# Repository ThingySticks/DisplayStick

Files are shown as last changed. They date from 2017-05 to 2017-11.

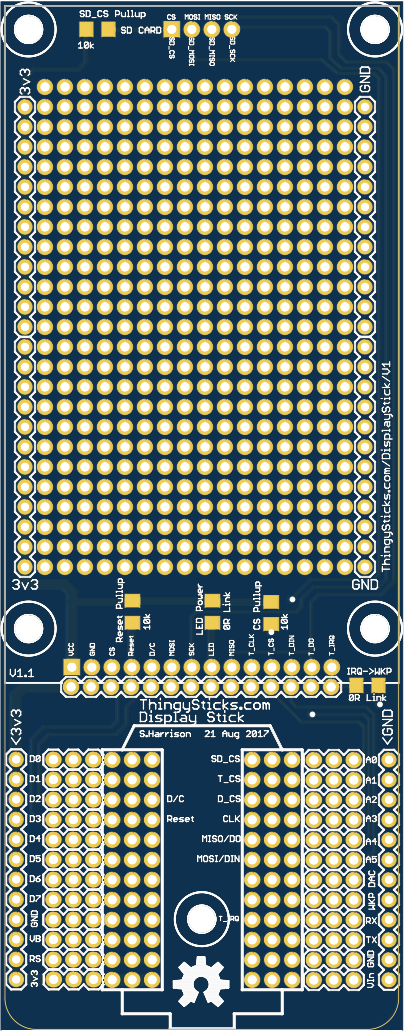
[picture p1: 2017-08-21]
Photon/V1/Images/PcbTop.png

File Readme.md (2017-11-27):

Photon Display Prototyping PCB.
================================

Prototype board for Particle Photon with 3.2" (eBay) display with prototype area underneath.

See individual versions for PCB specifics.

[Available on Tindie](https://www.tindie.com/products/ThingySticks/display-stick-for-a-28-display-and-photon/)

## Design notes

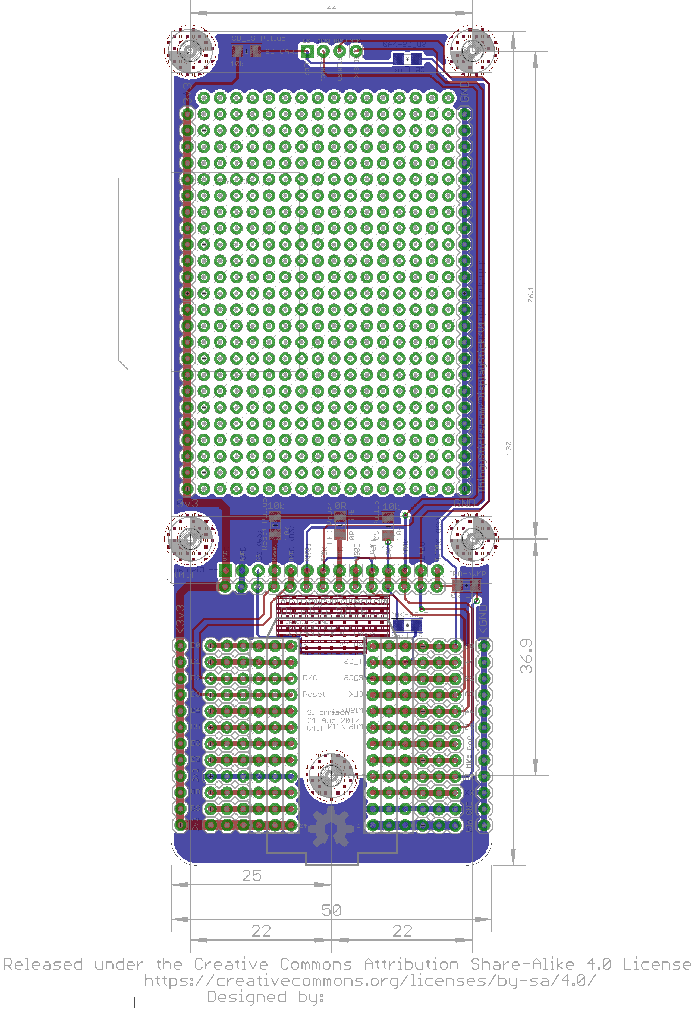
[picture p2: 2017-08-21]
Photon/V1/Images/PCBAllDesign.png

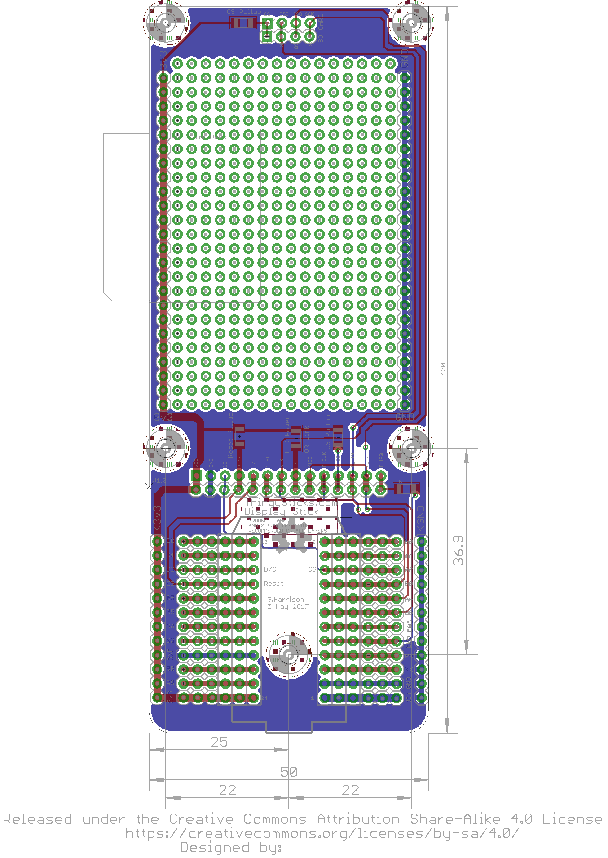
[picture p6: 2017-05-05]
Photon/V1/Images/v1.0/PCB-All.png

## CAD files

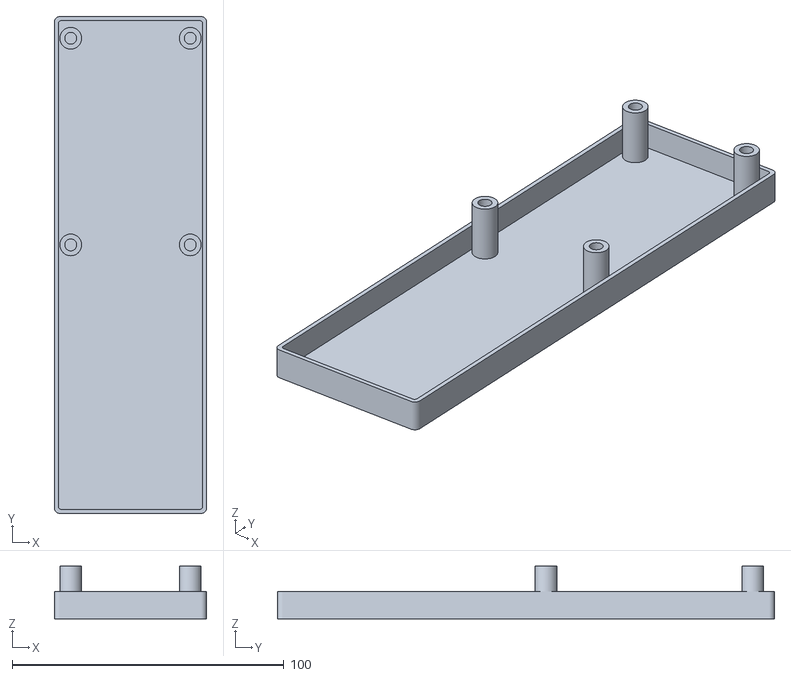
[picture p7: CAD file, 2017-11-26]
Photon/V1/Case/DisplayStickCaseForGPS.stl
56.0 x 183.0 x 19.4

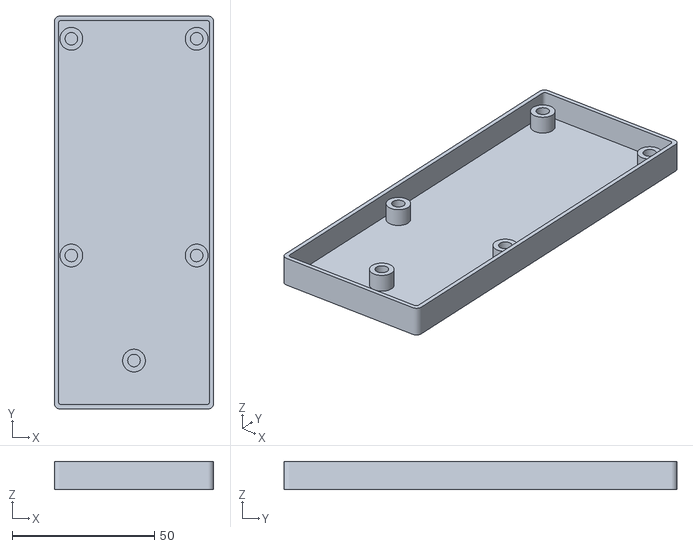
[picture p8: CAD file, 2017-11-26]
Photon/V1/Case/DisplayStickCase.stl
56.0 x 138.0 x 10.0

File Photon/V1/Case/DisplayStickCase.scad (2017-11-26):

$fn=80;

// Width (Note pcb does not centre align).
width = 56;

// Overall length /mm (without aerial 117mm, With aerial 125mm)
//length = 138;
length = 138 + 45; // with GPS

// Thickness of the base material.
baseHeight = 1.5;

// How height off the base the PCB wil lbe.
// 8mm gives a space for pins on the PCB
// used when piggubacking other pcbs.
//height = 8;
height = 18; // With GPS

//pcbYOffset = 3;
pcbYOffset = 3 + 45; // with GPS

incluedGpsModule = true;
// If including GPS raise height and length

// Diameter of the screw hole for the PCB mounts. 4.4mm works well for M3 heatfits.
pcbMountScrewHoleDiameter = 4.4;

// Diameter of the pins used to locate the PCB instead of screw holes.
pcbMountPinDiameter = 2.8;

module roundedCube(width, height, depth, cornerDiameter) {
//cornerDiameter = 5;
cornerRadius = cornerDiameter/2;

    translate([cornerDiameter/2,0,0]) {
        cube([width-cornerDiameter, height, depth]);
    }
    
    translate([0,cornerDiameter/2,0]) {
        cube([width, height-cornerDiameter, depth]);
    }
    
    translate([cornerRadius,cornerRadius,0]) {
        cylinder(d=cornerDiameter, h=depth);
    }
    
    translate([width-cornerRadius,cornerRadius,0]) {
        cylinder(d=cornerDiameter, h=depth);
    }
    
    translate([cornerRadius,height-cornerRadius,0]) {
        cylinder(d=cornerDiameter, h=depth);
    }
    
    translate([width-cornerRadius,height-cornerRadius,0]) {
        cylinder(d=cornerDiameter, h=depth);
    }
}

module screw(x,y, height) {
    translate([x,y, 0]) {
        cylinder(d=6.5, h=2);
    }
    
    translate([x,y, -4]) {
        cylinder(d=3, h=6);
    }
}

module pcb() {
    cube([50,130,1.6]);
    
    // Photon Screw mount
    screw(25, 14, height, baseHeight);
    
    // Display mounts.
    screw(3,14+36.9, height, baseHeight);
    screw(47,14+36.9, height, baseHeight);
    screw(3,14+36.9+76.1, height, baseHeight);
    screw(47,14+36.9+76.1, height, baseHeight);
}

module photon() {
    cube([20,38,13]);
        
    // USB
    translate([(20 - 8)/2, 0, 13]) {
        cube([8,5.5,3]);
    }
    
    // USB Plug
    translate([(20 - 12)/2, -20, 10]) {
        cube([12,22,7]);
    }
}

module display() {
    cube([50,85,13]);
}

module pcbMount(x,y, height, baseHeight) {
    translate([x,y, baseHeight-0.1]) {
        difference() {
            cylinder(d=8, h=height);
            cylinder(d=pcbMountScrewHoleDiameter, h=height);
        }
    }
}

module pcbMountPin(x,y, height, baseHeight) {
    translate([x,y, baseHeight-0.1]) {
        union() {
            cylinder(d=10, h=height);
            cylinder(d=pcbMountPinDiameter, h=height + 3);
        }
    }
}

module addPcbMounts() {
    // Use pins on the end two to make it easier to 
    
    // Photon Screw mount
    if (!incluedGpsModule) {
        pcbMount(25, 14, height, baseHeight);
    }
    
    // Display mounts.
    pcbMount(3,14+36.9, height, baseHeight);
    pcbMount(47,14+36.9, height, baseHeight);
    pcbMount(3,14+36.9+76.1, height, baseHeight);
    pcbMount(47,14+36.9+76.1, height, baseHeight);
}

module base() {       

    difference() {
        roundedCube(width, length, 10, 4);
        translate([1.5,1.5,baseHeight]) {
            roundedCube(width-3, length-3, 11, 2);
        }
    }
        
    
    translate([3,pcbYOffset,0]) {
        addPcbMounts();
    }
}

base();
showModels();

module showModels() {
    // Wall offset inside the box.
    translate([3,pcbYOffset,0]) {
        translate([0,0, baseHeight + height]) {
            %pcb();
        }

        translate([(50-20)/2, 0,  baseHeight + height + 1.6]) {
            %photon();
        }

        translate([0, 130 - 85, baseHeight + height + 1.6]) {
            %display();
        }
    }
}

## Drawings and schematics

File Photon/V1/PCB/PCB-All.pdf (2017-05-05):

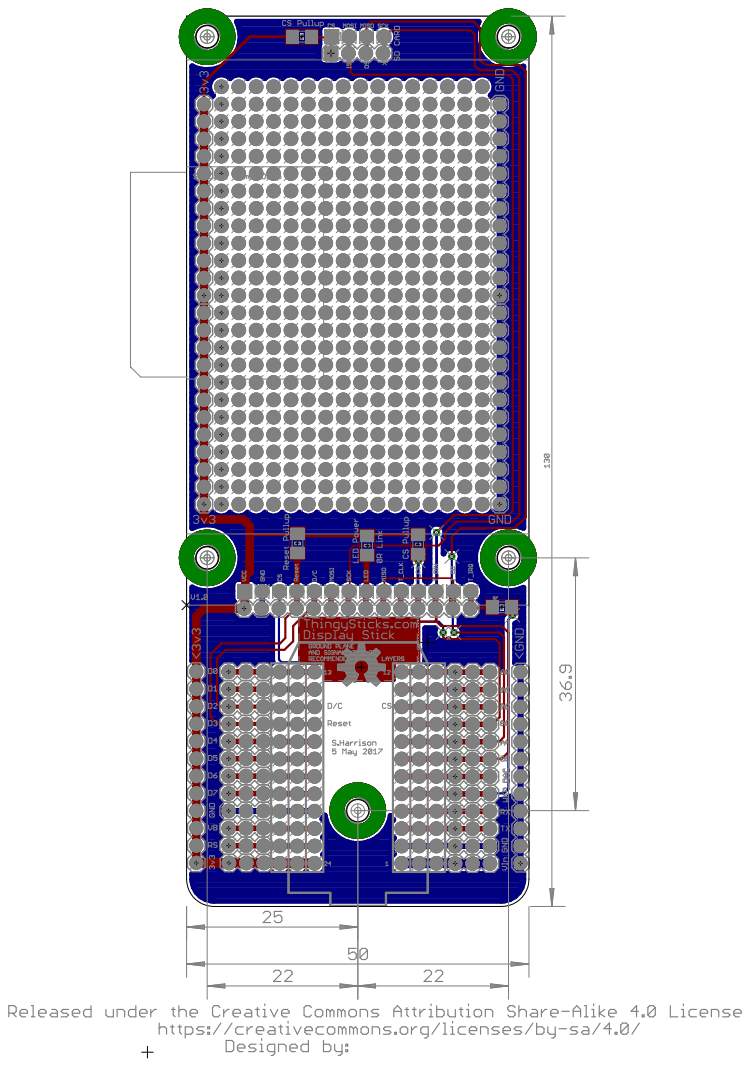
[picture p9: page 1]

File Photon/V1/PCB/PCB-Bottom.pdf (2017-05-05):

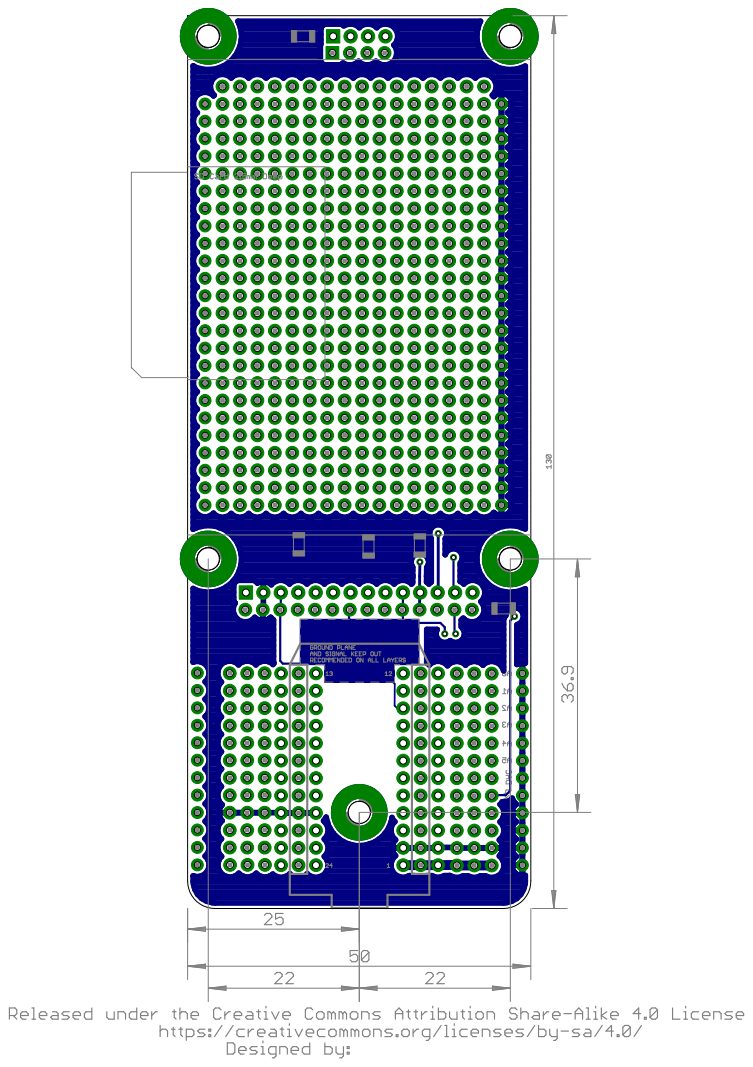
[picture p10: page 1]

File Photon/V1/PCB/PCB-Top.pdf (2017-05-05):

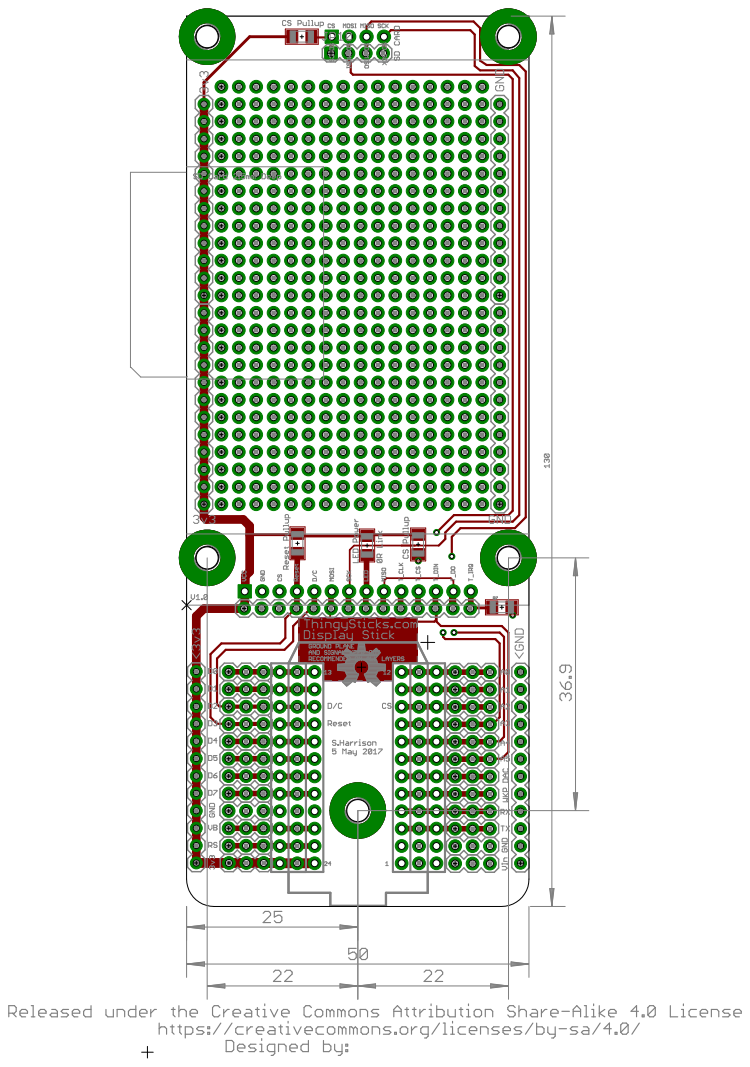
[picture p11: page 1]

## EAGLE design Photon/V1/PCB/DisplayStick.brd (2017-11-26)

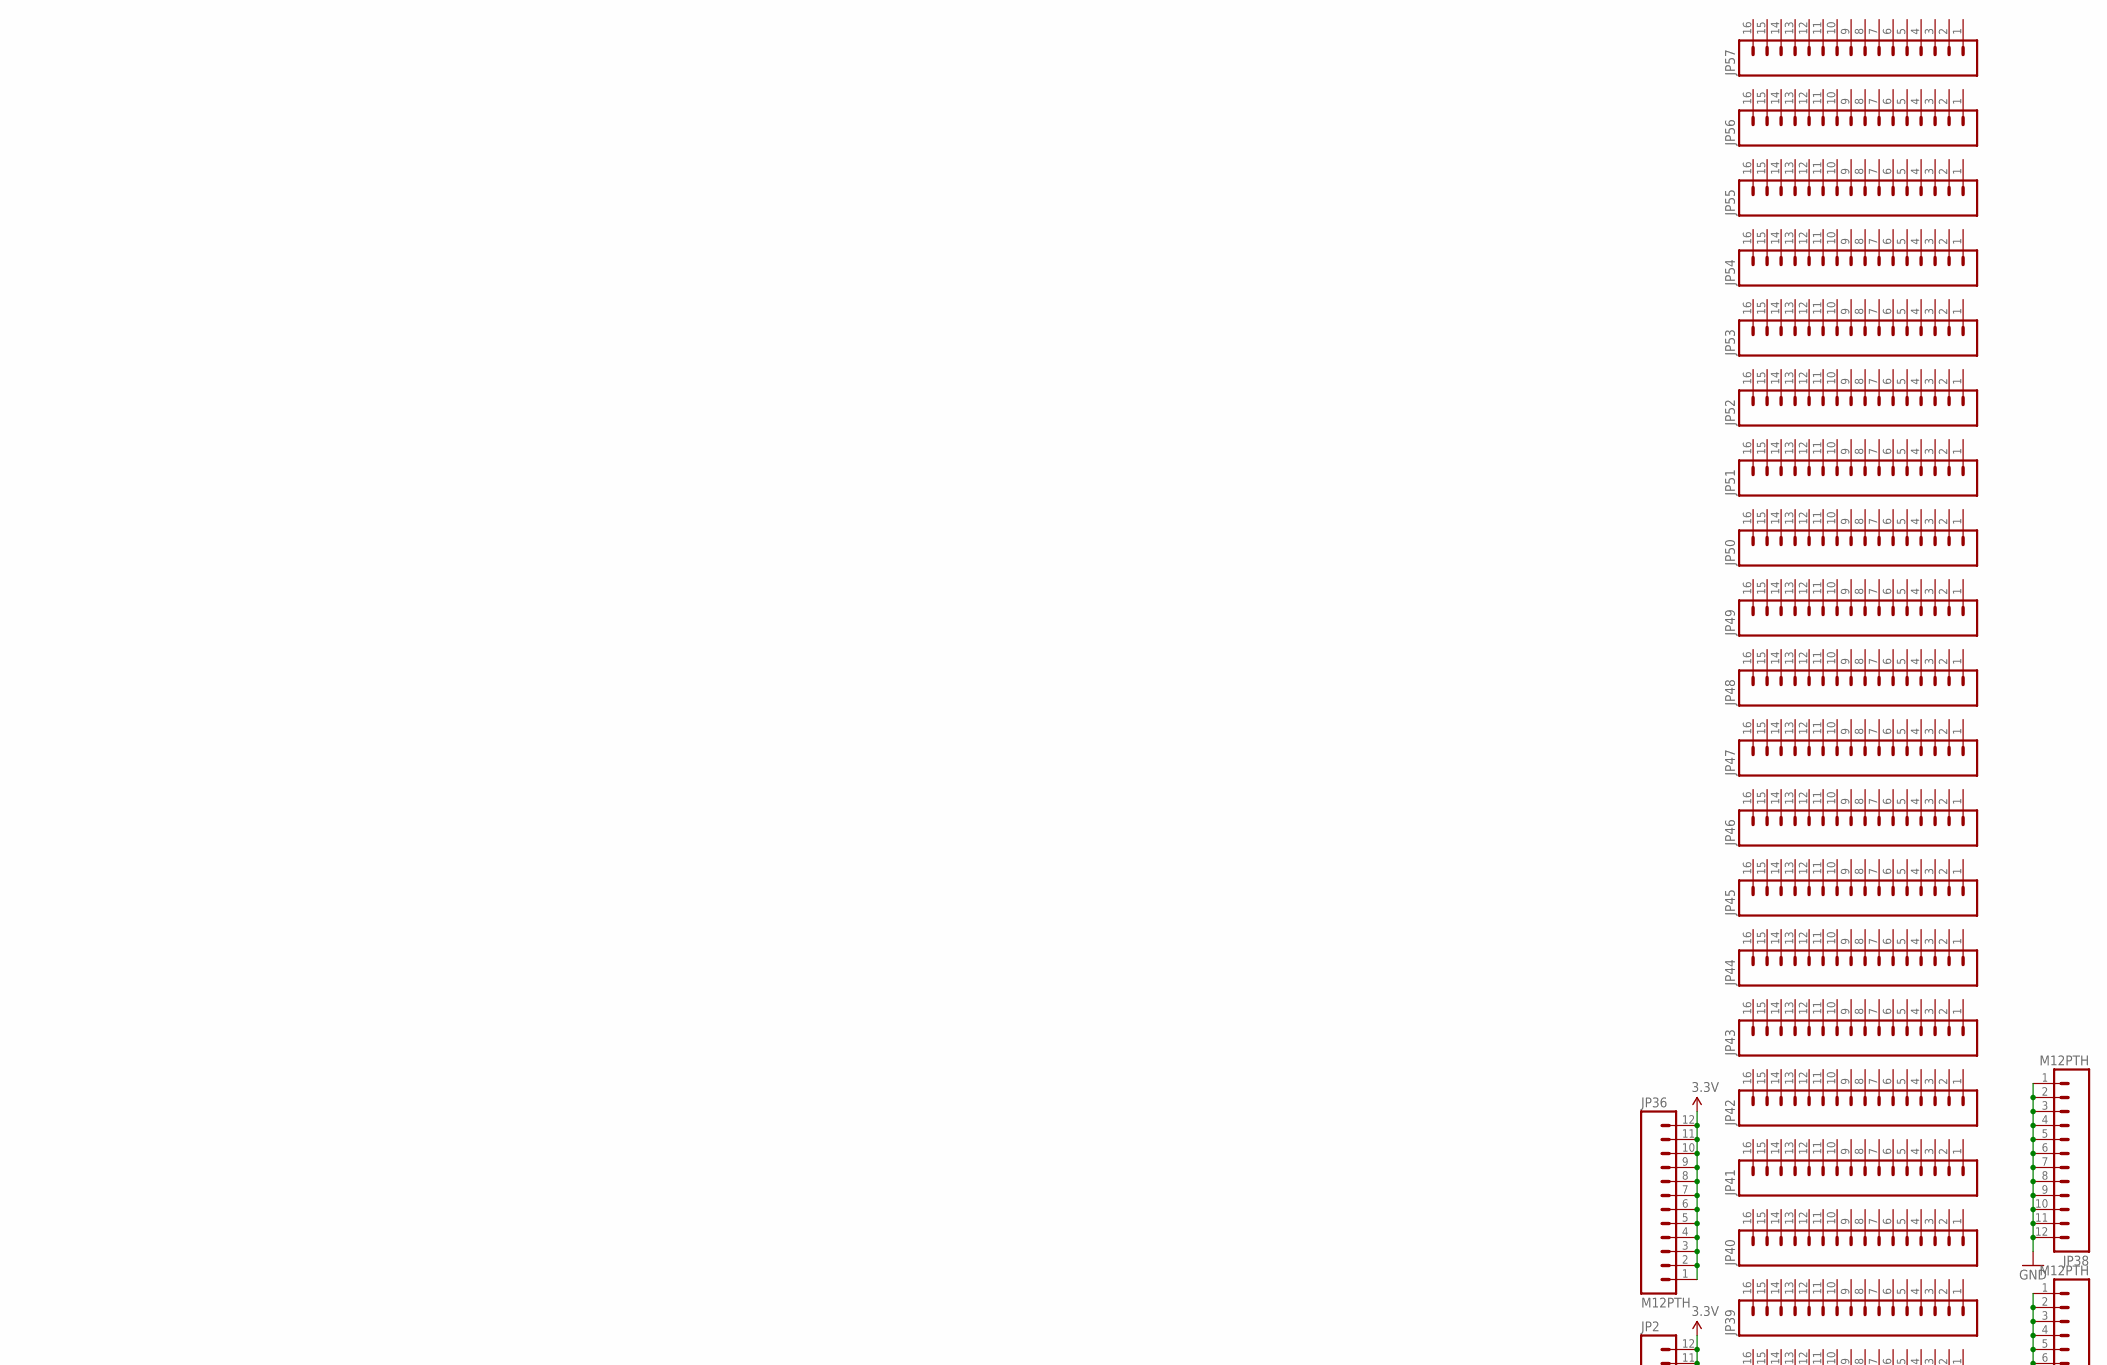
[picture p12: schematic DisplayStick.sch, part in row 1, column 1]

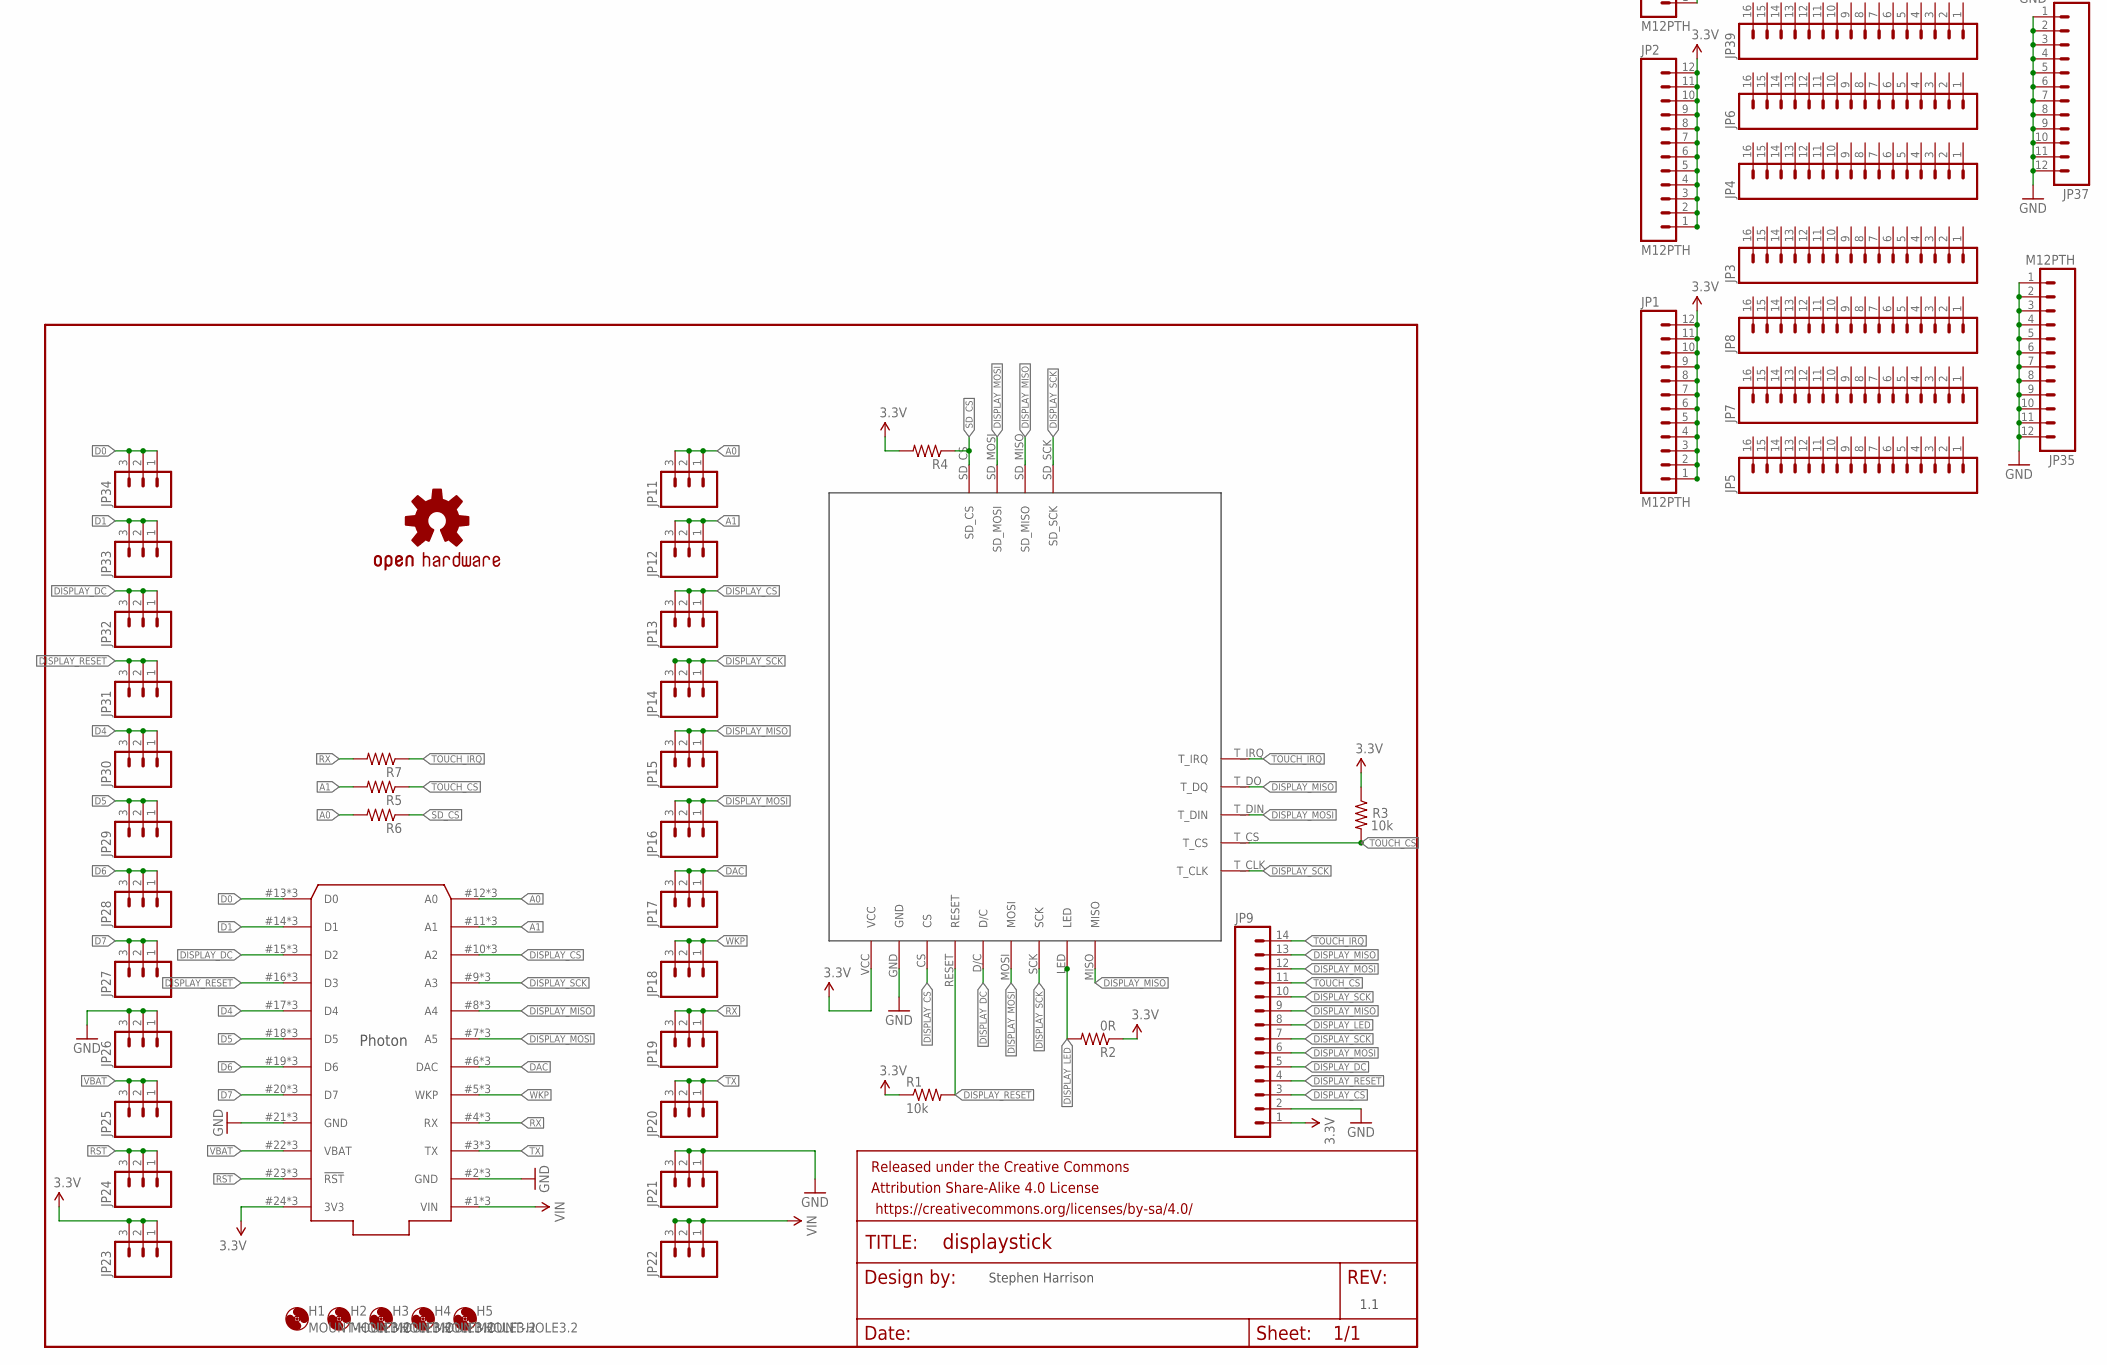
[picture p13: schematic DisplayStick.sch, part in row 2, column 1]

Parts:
FRAME1: FRAME-LETTER; CREATIVE_COMMONS
H1, H2, H3, H4, H5: MOUNT-HOLE3.2; 3,2
JP1, JP2, JP35, JP36, JP37, JP38: M12PTH; 1X12-SMALL-PADS
JP3, JP4, JP5, JP6, JP7, JP8, JP39, JP40, JP41, JP42, JP43, JP44, JP45, JP46, JP47, JP48, JP49, JP50, JP51, JP52, JP53, JP54, JP55, JP56, JP57: M161X16_NO_SILK; 1X16_NO_SILK
JP9: M14; 1X14
JP11, JP12, JP13, JP14, JP15, JP16, JP17, JP18, JP19, JP20, JP21, JP22, JP23, JP24, JP25, JP26, JP27, JP28, JP29, JP30, JP31, JP32, JP33, JP34: M03PTH; 1X03
LOGO1: OSHW-LOGOL; OSHW-LOGO-L
R1, R3: 10k; 1206
R2: 0R; 1206
R4, R5, R6, R7: RESISTOR1206; 1206
U$1: TJCTM240
U$3: PHOTON_WITH_STACKABLE_HEADERS; PHOTON_STACKABLE

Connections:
3.3V: JP1.1, JP1.2, JP1.3, JP1.4, JP1.5, JP1.6, JP1.7, JP1.8, JP1.9, JP1.10, JP1.11, JP1.12, JP2.1, JP2.2, JP2.3, JP2.4, JP2.5, JP2.6, JP2.7, JP2.8, JP2.9, JP2.10, JP2.11, JP2.12, JP9.1, JP23.1, JP23.2, JP23.3, JP36.1, JP36.2, JP36.3, JP36.4, JP36.5, JP36.6, JP36.7, JP36.8, JP36.9, JP36.10, JP36.11, JP36.12, R1.1, R2.1, R3.1, R4.2, U$1.VCC, U$3.24 (3V3), U$3.#24 (3V3), U$3.@24 (3V3)
A0: JP11.1, JP11.2, JP11.3, R6.2, U$3.12 (A0), U$3.#12 (A0), U$3.@12 (A0)
A1: JP12.1, JP12.2, JP12.3, R5.2, U$3.11 (A1), U$3.#11 (A1), U$3.@11 (A1)
D0: JP34.1, JP34.2, JP34.3, U$3.13 (D0), U$3.#13 (D0), U$3.@13 (D0)
D1: JP33.1, JP33.2, JP33.3, U$3.14 (D1), U$3.#14 (D1), U$3.@14 (D1)
D4: JP30.1, JP30.2, JP30.3, U$3.17 (D4), U$3.#17 (D4), U$3.@17 (D4)
D5: JP29.1, JP29.2, JP29.3, U$3.18 (D5), U$3.#18 (D5), U$3.@18 (D5)
D6: JP28.1, JP28.2, JP28.3, U$3.19 (D6), U$3.#19 (D6), U$3.@19 (D6)
D7: JP27.1, JP27.2, JP27.3, U$3.20 (D7), U$3.#20 (D7), U$3.@20 (D7)
DAC: JP17.1, JP17.2, JP17.3, U$3.6 (DAC), U$3.#6 (DAC), U$3.@6 (DAC)
DISPLAY_CS: JP9.3, JP13.1, JP13.2, JP13.3, U$1.CS, U$3.10 (A2), U$3.#10 (A2), U$3.@10 (A2)
DISPLAY_DC: JP9.5, JP32.1, JP32.2, JP32.3, U$1.D/C, U$3.15 (D2), U$3.#15 (D2), U$3.@15 (D2)
DISPLAY_LED: JP9.8, R2.2, U$1.LED
DISPLAY_MISO: JP9.9, JP9.13, JP15.1, JP15.2, JP15.3, U$1.MISO, U$1.SD_MISO, U$1.T_DO (T_DQ), U$3.8 (A4), U$3.#8 (A4), U$3.@8 (A4)
DISPLAY_MOSI: JP9.6, JP9.12, JP16.1, JP16.2, JP16.3, U$1.MOSI, U$1.SD_MOSI, U$1.T_DIN, U$3.7 (A5), U$3.#7 (A5), U$3.@7 (A5)
DISPLAY_RESET: JP9.4, JP31.1, JP31.2, JP31.3, R1.2, U$1.RESET, U$3.16 (D3), U$3.#16 (D3), U$3.@16 (D3)
DISPLAY_SCK: JP9.7, JP9.10, JP14.1, JP14.2, JP14.3, U$1.SCK, U$1.SD_SCK, U$1.T_CLK, U$3.9 (A3), U$3.#9 (A3), U$3.@9 (A3)
GND: JP9.2, JP21.1, JP21.2, JP21.3, JP26.1, JP26.2, JP26.3, JP35.1, JP35.2, JP35.3, JP35.4, JP35.5, JP35.6, JP35.7, JP35.8, JP35.9, JP35.10, JP35.11, JP35.12, JP37.1, JP37.2, JP37.3, JP37.4, JP37.5, JP37.6, JP37.7, JP37.8, JP37.9, JP37.10, JP37.11, JP37.12, JP38.1, JP38.2, JP38.3, JP38.4, JP38.5, JP38.6, JP38.7, JP38.8, JP38.9, JP38.10, JP38.11, JP38.12, U$1.GND, U$3.2 (GND), U$3.21 (GND), U$3.#2 (GND), U$3.#21 (GND), U$3.@2 (GND), U$3.@21 (GND)
RST: JP24.1, JP24.2, JP24.3, U$3.23 (!RST), U$3.#23 (!RST), U$3.@23 (!RST)
RX: JP19.1, JP19.2, JP19.3, R7.2, U$3.4 (RX), U$3.#4 (RX), U$3.@4 (RX)
SD_CS: R4.1, R6.1, U$1.SD_CS
TOUCH_CS: JP9.11, R3.2, R5.1, U$1.T_CS
TOUCH_IRQ: JP9.14, R7.1, U$1.T_IRQ
TX: JP20.1, JP20.2, JP20.3, U$3.3 (TX), U$3.#3 (TX), U$3.@3 (TX)
VBAT: JP25.1, JP25.2, JP25.3, U$3.22 (VBAT), U$3.#22 (VBAT), U$3.@22 (VBAT)
VIN: JP22.1, JP22.2, JP22.3, U$3.1 (VIN), U$3.#1 (VIN), U$3.@1 (VIN)
WKP: JP18.1, JP18.2, JP18.3, U$3.5 (WKP), U$3.#5 (WKP), U$3.@5 (WKP)

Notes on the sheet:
1.1
Stephen Harrison

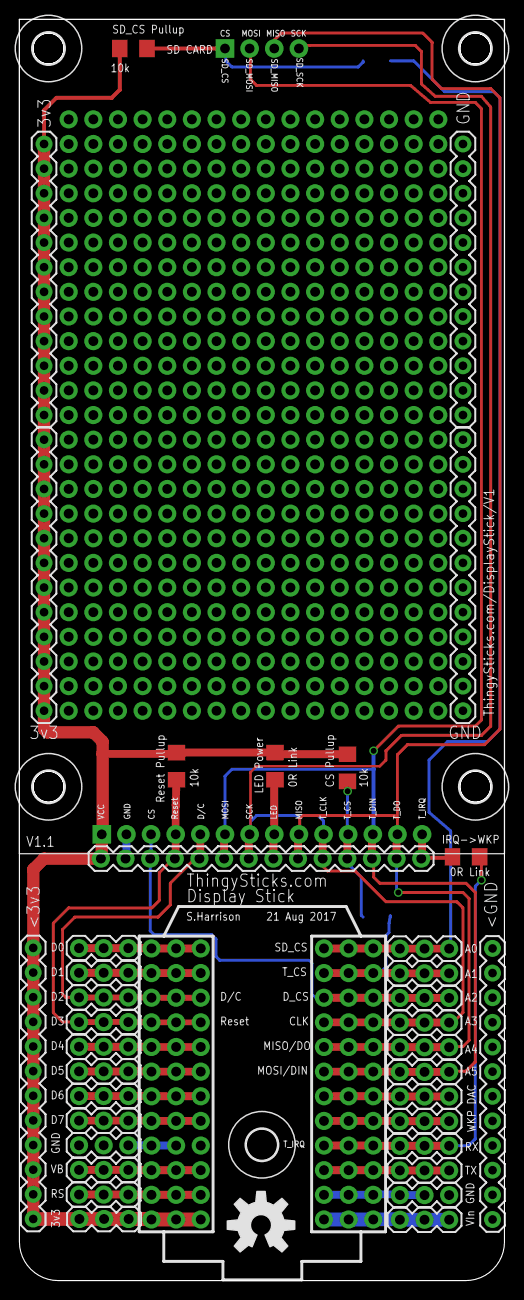
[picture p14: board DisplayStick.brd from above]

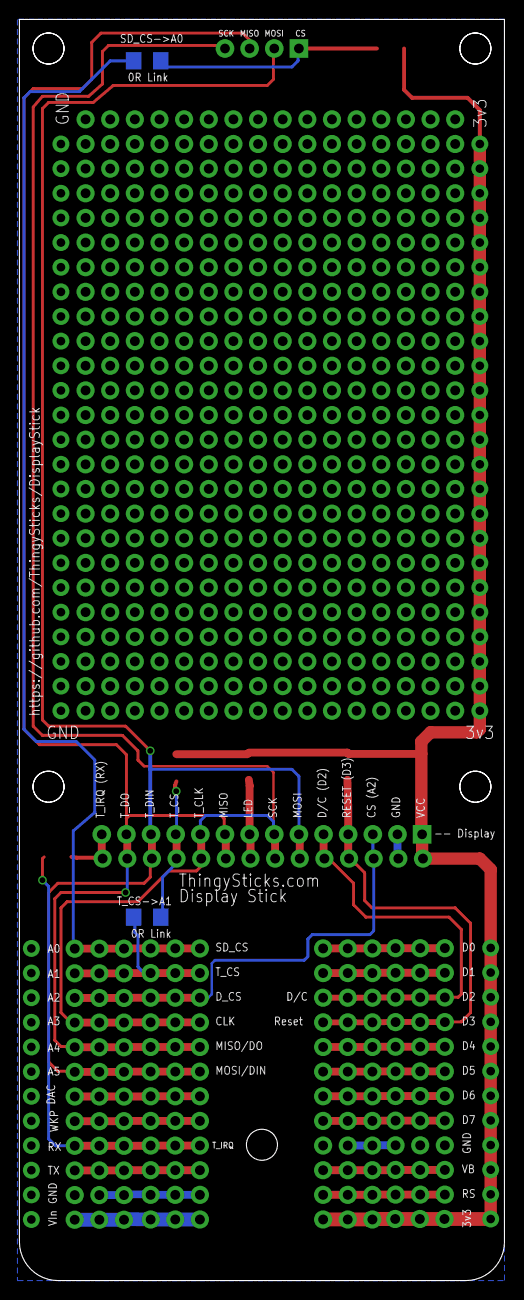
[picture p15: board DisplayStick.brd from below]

Board: 2 copper layers, 50.0 x 130.0 mm, 72 parts (2 on the bottom side), 27 nets.

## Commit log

2017-05-05 Initial version.
    [DisplayStick.brd, DisplayStick.sch]
2017-08-21 Added links for touch and sd card chip selects. Removed upper J10 4 pin connector so it's more obvious which connector the display should go into.
    Bumped to V1.1
    [DisplayStick.brd, DisplayStick.sch]
2017-11-26 Moved location of prototyping holes/connectors.
    [DisplayStick.brd]
2017-11-26 Added PCB images.
2017-11-26 Work in progress case...
    [DisplayStickCase.scad, DisplayStickCase.stl, DisplayStickCaseForGPS.stl]

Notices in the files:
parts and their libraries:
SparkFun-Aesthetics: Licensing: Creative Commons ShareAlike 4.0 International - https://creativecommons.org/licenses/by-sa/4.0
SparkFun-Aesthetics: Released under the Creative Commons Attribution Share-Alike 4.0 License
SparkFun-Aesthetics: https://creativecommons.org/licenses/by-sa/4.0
